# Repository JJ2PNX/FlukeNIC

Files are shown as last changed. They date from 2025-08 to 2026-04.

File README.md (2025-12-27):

# FlukeNIC - Fluke 884x Web Control & Logger Card

## Overview
The Fluke 884x is an outstanding multimeter.  
Even after 40+ years since its production, most units still function properly and maintain excellent accuracy.  
It's likely more reliable than many cheap modern benchtop meters.  
Its value increases when used in ways unique to benchtop instruments, beyond what handheld meters offer.  
GPIB was the traditional method, but a bit far from modern solution.  
I developed built-in web control and logger card that replaces the original GPIB board.  
NIC ... acronym of Network Interface Card.

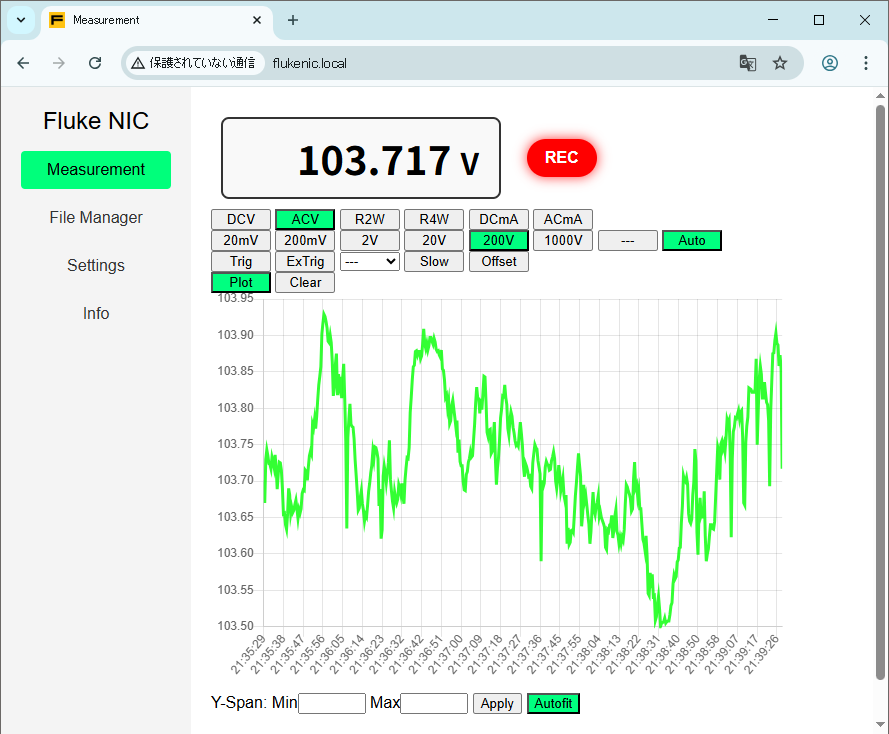
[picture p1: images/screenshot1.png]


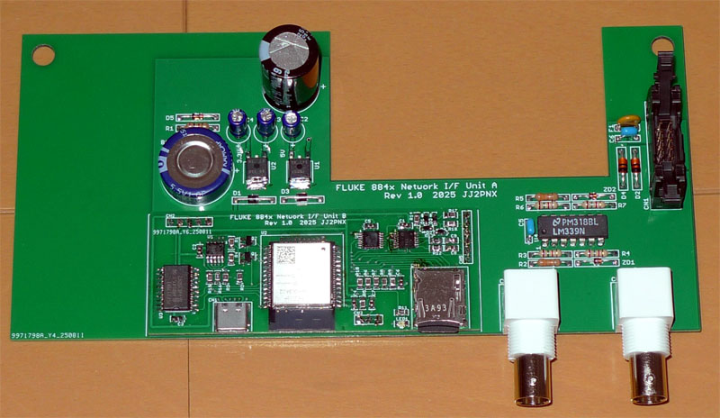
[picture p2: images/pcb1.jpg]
pcb1


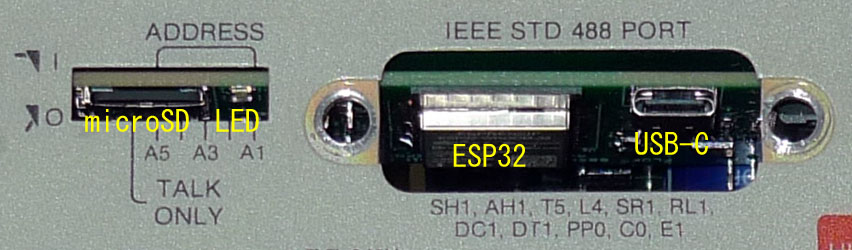
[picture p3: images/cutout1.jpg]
cutout1


---

## Features of This Card
- **WiFi Connectivity**
- **Web-based Control**
- **SD Card Stand-alone Logging**
- **Built-in, No modifications to the main unit required**

---

## How to Get

### 1. Hardware
Currently, no pre-assembled units or kits are available. Please build from the PCB.  
PCB fabrication files (UnitA/B.zip) are for JLCPCB.  
All necessary design materials are in the *hardware* directory.

### 2. Firmware
#### Method 1: Using ESP-IDF

1. Set up the ESP-IDF environment.
2. Clone the repository.
3. Refer to `firmware/README.md` for firmware download instructions.

#### Method 2: Using Flash Download Tool

1. Download **Flash Download Tool** from Espressif.  
   https://docs.espressif.com/projects/esp-test-tools/en/latest/esp32/production_stage/tools/flash_download_tool.html
2. Download `merge.bin` from the `firmware` directory to flash memory at address `0x0`.

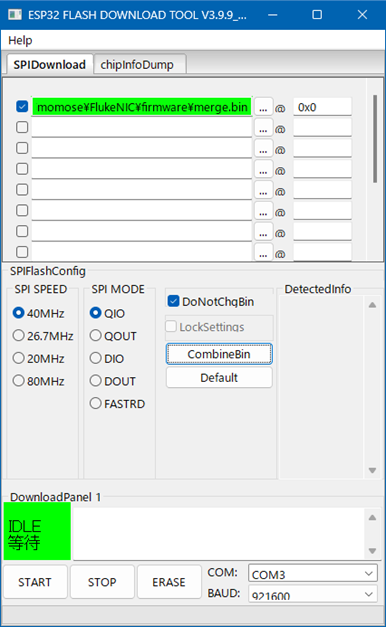
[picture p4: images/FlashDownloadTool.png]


---

## Help / How to Use

### 1. WiFi Connection
By default, FlukeNIC operates as a WiFi access point (AP).
- **SSID:** FlukeNIC  
- **Password:** 88408842  
- **IP Address:** 192.168.4.1  

You can configure WiFi Station settings by connecting to this AP, or by using the WPS push-button method.

#### WPS Push-Button Setup

1. Press the **SRQ** button repeatedly until the **SRQ** indicator lights.
2. When WPS succeeds, the **SRQ** indicator turns off and the **LISTEN** indicator turns on.

Settings are saved to flash memory, so the **LISTEN** indicator should light automatically upon the next power-on.

**Fluke Indicator Summary:**
| Indicator | Meaning |
|---|---|
| SRQ | WiFi WPS Request |
| LISTEN | WiFi Associated |
| TALK | Logging is Active |ESP_ERROR_CHECK

---

### 2. Browser Access
Currently, only DHCP-assigned IPs are supported.  
In most cases, you can access it via:
http://flukenic.local/
If that doesn't work, check the DHCP-assigned IP address on your WiFi router.  
If you got the web interface, you probably won’t need further instructions!

---

### 3. Logging
microSD card is required.  
Start/stop operation can be performed using web-control or front panel **LOCAL** button.  
When logging is active, **TALK** indicator lights up.  
Results can be obtained using File Manager menu, or directly from microSD card, But hot swap is not supported.

---

### 4. Configuration
- Be sure to select the correct model (**8840 / 8842**).
- Other settings are optional.
- All configurations are saved to flash memory.

---

### 5. Troubleshooting
Communication with the Fluke unit is based on reverse-engineering and may malfunction with unexpected inputs.  
In such cases, use the **“Last bytes”** function in the Info menu to inspect the last communication log.  
Feel free to contact me — there may be a fix. Contributions are welcome!

---

### 6. Additional Notes
- SD card hot-swapping is not supported.  
Please insert or remove the card only when the power is off.
- BNC output is not implimented now.

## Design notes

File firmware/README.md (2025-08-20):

## Build and Flash Firmware

```bash
# Move to the firmware directory
$ cd firmware

# Initialize and update submodules
$ git submodule init
$ git submodule update

# Build the firmware (this will take a while)
$ idf.py build

# Flash to device (change the device name to match your PC)
$ idf.py -p /dev/ttyUSB0 flash

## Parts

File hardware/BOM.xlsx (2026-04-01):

UNIT A
 | Parts | Qty | Value | Description
 | BC1 | 1 | 1F | EDLC 1F/5.5V SE-5R5-D105VY (for RTC backup, optional)
 | C1 | 1 | 4700/16V | Electrolytic cap
 | C2, C3, C4 | 3 | 10/16V | Electrolytic cap
 | C5, C6 | 2 | 0.1 | Ceramic cap
 | CN1 | 1 | PS-10PE-D4T2-M1E | Pin header w/Lock
 | CN2, CN3 | 2 | B-057-HP | BNC receptacle
 | D1, D3 | 2 | 1S4 | Low VF generic rect 1A
 | D2, D4 | 2 | 1N4007 | Generic rect 1A
 | D5 | 1 | 1N4148 | Low IR recommended (for RTC backup)
 | F1 | 1 | Not use, use jumper instead
 | R1 | 1 | 1k | Generic resistor
 | R2, R5 | 2 | 33k | Generic resistor
 | R3, R4, R6, R7 | 4 | 1.5k | Generic resistor
 | U1 | 1 | NJM7805SDL1 | Voltage reg 5V, Package TO-252-3
 | U2 | 1 | NJM2845DL1-33 | Voltage reg 3.3V, Low drop, Package TO-252-3
 | U3 | 1 | UNITB
 | U4 | 1 | LM339N
 | ZD1, ZD2 | 2 | RD3.9 | Zener 3.9V
UNIT B
 | Parts | Qty | Value | Description
 | C1, C2, C3, C4, C5, C6, C7 | 7 | 0.1 | Ceramic cap 2012
 | C8, C9 | 2 | 0.01 | Ceramic cap 2012
 | CN1 | 1 | 5077CR-16-SMC2-BK-TR | USB-C jack
 | CN2 | 1 | CON_5P | Pin header single line 100mil
 | CN3 | 1 | CON_3P | Pin header single line 100mil
 | CN4 | 1 | DM3AT-SF-PEJM5 | microSD card socket
 | CN5 | 1 | CON_6P | Pin header single line 100mil
 | D1, D2, D3, D4 | 4 | 1SS355 | Generic SW diode SOD-323
 | LED1 | 1 | PG1112H-TR | Generic LED 2125
 | Q1, Q2 | 2 | 2SC2712 | Generic NPN SC-59
 | R1, R4, R5, R6, R7, R8, R9, R10, R14 | 9 | 10k | Generic resistor 2012
 | R11, R12, R13 | 3 | 470 | Generic resistor 2012
 | R15, R16 | 2 | 3.3k | Generic resistor 2012
 | R17, R18 | 2 | 1k | Generic resistor 2012
 | R2, R3 | 2 | 5.1k | Generic resistor 2012
 | U1 | 1 | CH340K | USB-Serial converter, Backside pad soldering is not required
 | U2 | 1 | ESP-WROOM-32E | Use last letter 'E', Flash >= 4M, Backside pad soldering is not required
 | U3 | 1 | PCF2129 | RTC (optional)
 | U4 | 1 | 74ACT14 | Hex schmitt trigger 5V, TTL input, TSSOP14
 | U5 | 1 | 74LCX14 | Hex schmitt trigger 3.3V, 5V tolerant, TSSOP14

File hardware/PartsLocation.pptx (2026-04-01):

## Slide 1

UNIT A

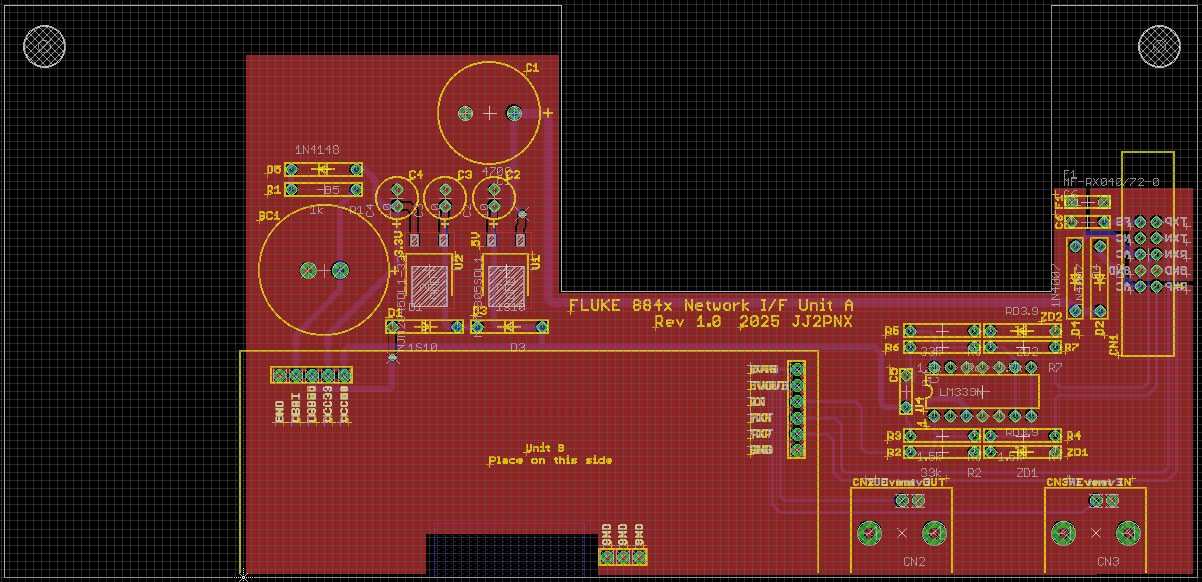
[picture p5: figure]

4700

1N4148

1k

1F

10

10

10

5V

1S4

Jumper

0.1

3V3

1S4

1N4007

1N4007

0.1

33k

1.5k

1.5k

RD3.9

33k

1.5k

1.5k

RD3.9

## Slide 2

UNIT B

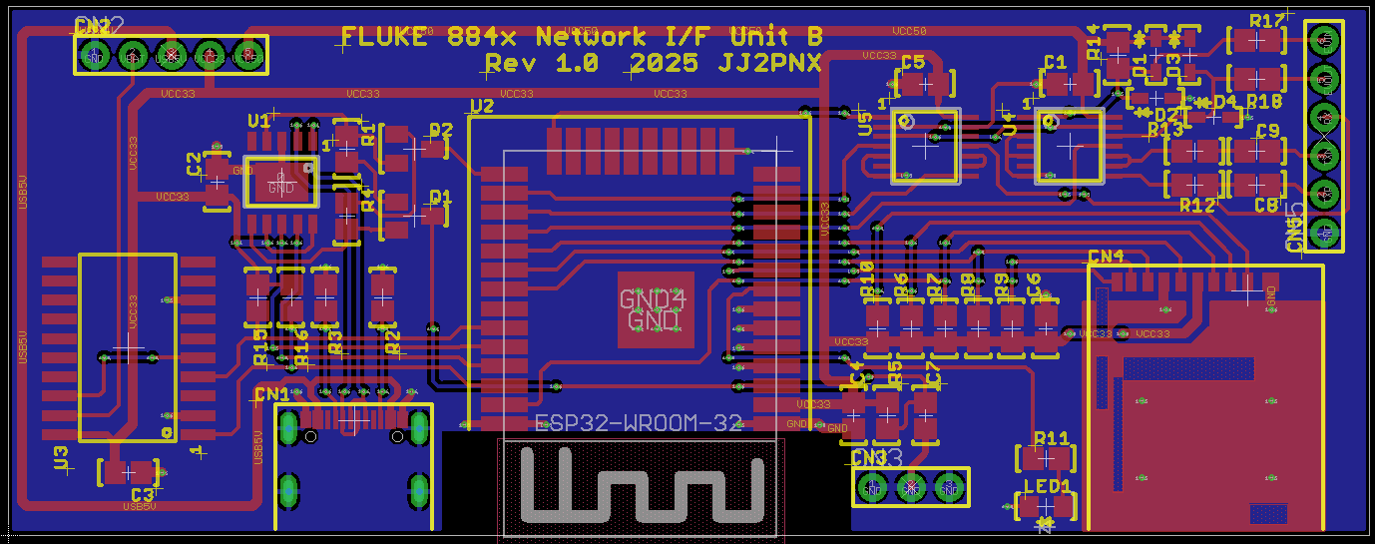
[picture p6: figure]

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
3.3k

10k

470

470

0.01

0.01

3.3k

5.1k

10k

5.1k

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
0.1u x 7
0.01u x 2

Res
470 x3
1k x2
3.3k x2
5.1k x2
10k x9

0.1

0.01

470

1K

3.3k

5.1k

10k

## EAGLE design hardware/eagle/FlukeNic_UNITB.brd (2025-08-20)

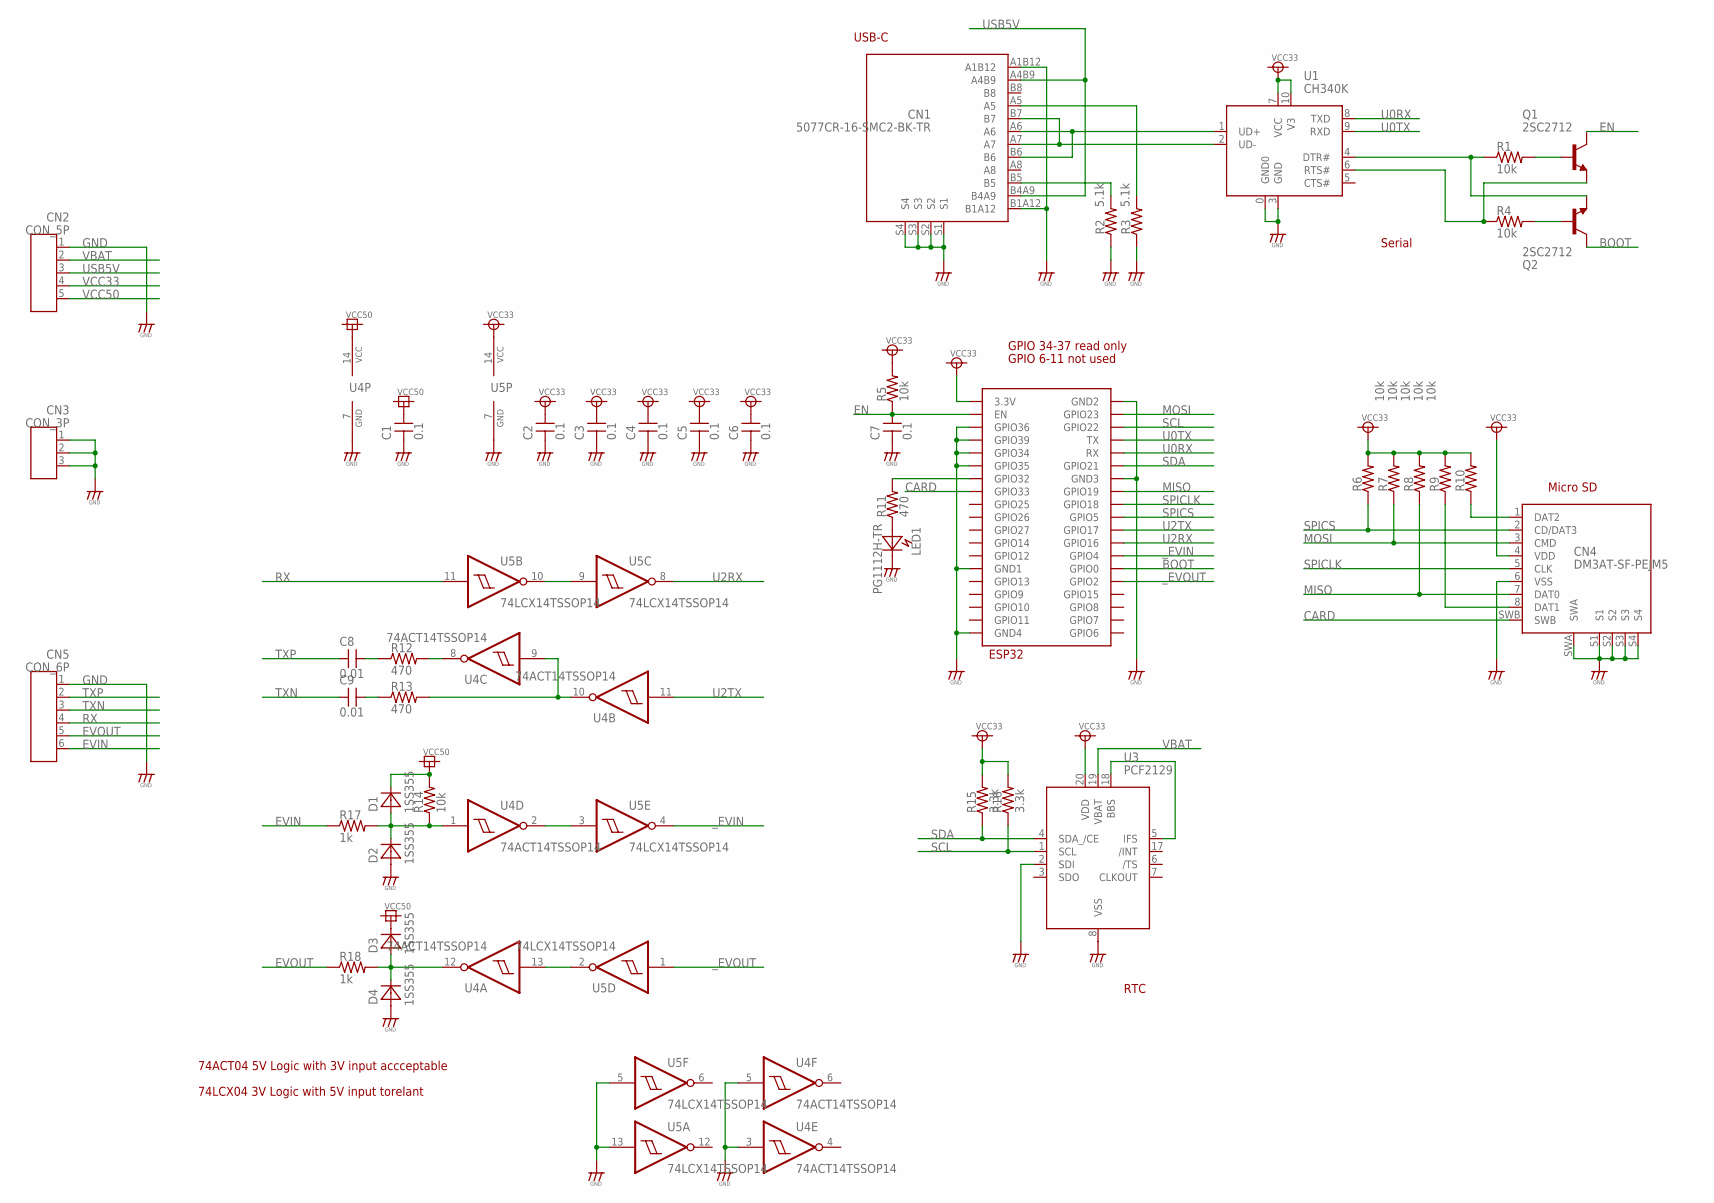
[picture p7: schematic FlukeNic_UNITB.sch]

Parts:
C1, C2, C3, C4, C5, C6, C7: 0.1; C2012
C8, C9: 0.01; C2012
CN1: 5077CR-16-SMC2-BK-TR
CN2: CON_5P; CON_HDR_SIP5
CN3: CON_3P; CON_HDR_SIP3
CN4: DM3AT-SF-PEJM5
CN5: CON_6P; CON_HDR_SIP6
D1, D2, D3, D4: 1SS355; SOD323
LED1: PG1112H-TR; LED2125
Q1, Q2: 2SC2712; SC59
R1, R4, R5, R6, R7, R8, R9, R10, R14: 10k; R2012
R2, R3: 5.1k; R2012
R11, R12, R13: 470; R2012
R15, R16: 3.3k; R2012
R17, R18: 1k; R2012
U1: CH340K; ESSOP10
U2: ESP32-WROOM
U3: PCF2129; SO20
U4: 74ACT14TSSOP14; TSSOP14
U5: 74LCX14TSSOP14; TSSOP14

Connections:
BBS: U3.5 (IFS), U3.18 (BBS)
BOOT: Q2.C, U2.IO0 (GPIO0)
CARD: CN4.SWB, U2.IO33 (GPIO33)
DAT1: CN4.8 (DAT1), R9.1
DAT2: CN4.1 (DAT2), R10.1
EN: C7.2, Q1.C, R5.1, U2.EN
EVIN: CN5.6, R17.1
EVOUT: CN5.5, R18.1
GND: C1.1, C2.1, C3.1, C4.1, C5.1, C6.1, C7.1, CN1.A1B12, CN1.B1A12, CN1.S1, CN1.S2, CN1.S3, CN1.S4, CN2.1, CN3.1, CN3.2, CN3.3, CN4.6 (VSS), CN4.S1, CN4.S2, CN4.S3, CN4.S4, CN4.SWA, CN5.1, D2.1 (A), D4.1 (A), LED1.K, R2.1, R3.1, U1.0 (GND0), U1.3 (GND), U2.GND1, U2.GND2, U2.GND3, U2.GND4, U2.IO34 (GPIO34), U2.IO35 (GPIO35), U2.SENSOR_VN (GPIO39), U2.SENSOR_VP (GPIO36), U3.2 (SDI), U3.8 (VSS), U4.3 (I), U4.5 (I), U4.7 (GND), U5.5 (I), U5.7 (GND), U5.13 (I)
MISO: CN4.7 (DAT0), R8.1, U2.IO19 (GPIO19)
MOSI: CN4.3 (CMD), R7.1, U2.IO23 (GPIO23)
unnamed: U4.13 (I), U5.2 (O)
unnamed: U4.2 (O), U5.3 (I)
unnamed: D1.1 (A), D2.2 (K), R14.1, R17.2, U4.1 (I)
unnamed: D3.1 (A), D4.2 (K), R18.2, U4.12 (O)
unnamed: R13.2, U4.9 (I), U4.10 (O)
unnamed: R12.2, U4.8 (O)
unnamed: U5.9 (I), U5.10 (O)
unnamed: C8.2, R12.1
unnamed: C9.2, R13.1
unnamed: LED1.A, R11.1
unnamed: Q1.B, R1.2
unnamed: Q2.B, R4.2
unnamed: CN1.B5, R2.2
unnamed: CN1.A5, R3.2
unnamed: Q2.E, R1.1, U1.4 (DTR#)
unnamed: Q1.E, R4.1, U1.6 (RTS#)
RX: CN5.4, U5.11 (I)
SCL: R16.1, U2.IO22 (GPIO22), U3.1 (SCL)
SDA: R15.1, U2.IO21 (GPIO21), U3.4 (SDA_/CE)
SPICLK: CN4.5 (CLK), U2.IO18 (GPIO18)
SPICS: CN4.2 (CD/DAT3), R6.1, U2.IO5 (GPIO5)
STATUS: R11.2, U2.IO32 (GPIO32)
TXN: C9.1, CN5.3
TXP: C8.1, CN5.2
U0RX: U1.8 (TXD), U2.RX
U0TX: U1.9 (RXD), U2.TX
U2RX: U2.IO16 (GPIO16), U5.8 (O)
U2TX: U2.IO17 (GPIO17), U4.11 (I)
UD+: CN1.A6, CN1.B6, U1.1 (UD+)
UD-: CN1.A7, CN1.B7, U1.2 (UD-)
USB5V: CN1.A4B9, CN1.B4A9, CN2.3
VBAT: CN2.2, U3.19 (VBAT)
VCC33: C2.2, C3.2, C4.2, C5.2, C6.2, CN2.4, CN4.4 (VDD), R5.2, R6.2, R7.2, R8.2, R9.2, R10.2, R15.2, R16.2, U1.7 (VCC), U1.10 (V3), U2.3V3 (3.3V), U3.20 (VDD), U5.14 (VCC)
VCC50: C1.2, CN2.5, D1.2 (K), D3.2 (K), R14.2, U4.14 (VCC)
_EVIN: U2.IO4 (GPIO4), U5.4 (O)
_EVOUT: U2.IO2 (GPIO2), U5.1 (I)

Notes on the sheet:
GPIO 6-11 not used
GPIO 34-37 read only
USB-C
Micro SD
RTC
Serial
74ACT04 5V Logic with 3V input accceptable
74LCX04 3V Logic with 5V input torelant

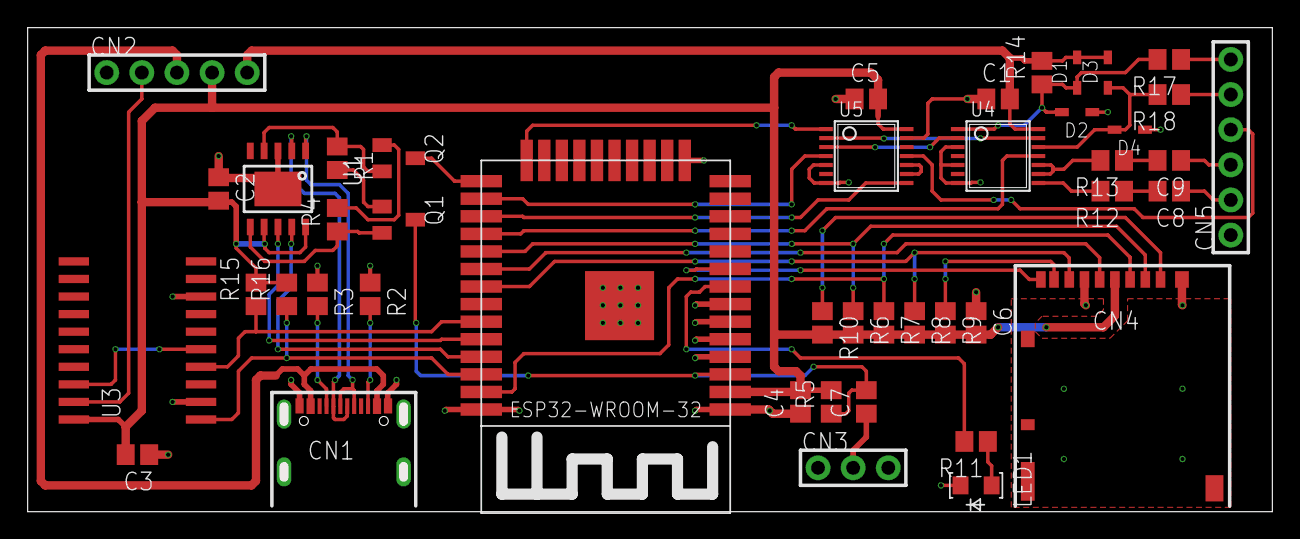
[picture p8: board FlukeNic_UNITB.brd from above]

Board: 2 copper layers, 90.0 x 35.0 mm, 44 parts (0 on the bottom side), 47 nets.

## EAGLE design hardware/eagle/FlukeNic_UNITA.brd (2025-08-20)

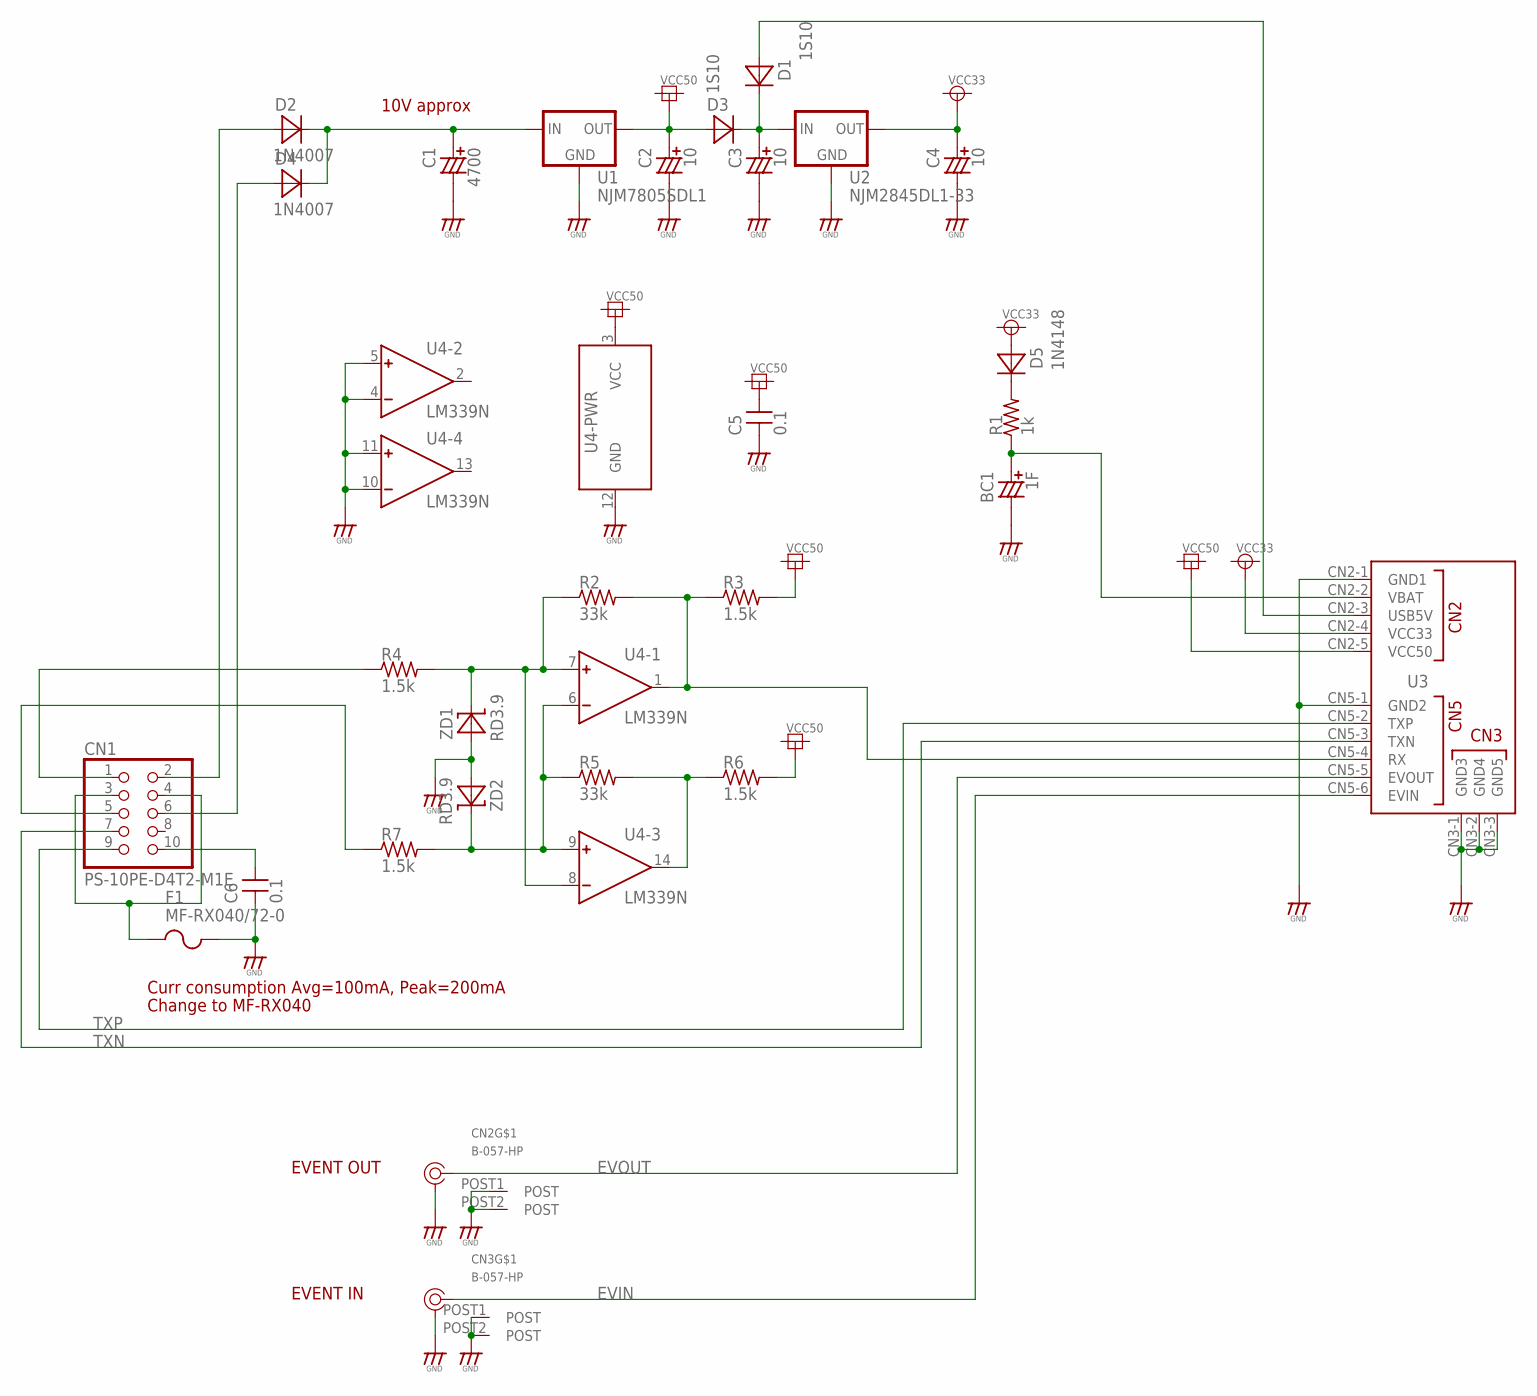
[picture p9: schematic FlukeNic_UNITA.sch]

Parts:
BC1: 1F; SE-5R5-D105VY
C1: 4700; CCAP_16
C2, C3, C4: 10; CCAP_6.5
C5, C6: 0.1; CAP_DIP_2
CN1: PS-10PE-D4T2-M1E
CN2, CN3: B-057-HP
D1, D3: 1S10; DIODE_4_1MM
D2, D4: 1N4007; DIODE_4_1MM
D5: 1N4148; DIODE_4
F1: MF-RX040/72-0; AX_08X02_2P_200
R1: 1k; R_0.25W_4
R2, R5: 33k; R_0.25W_4
R3, R4, R6, R7: 1.5k; R_0.25W_4
U1: NJM7805SDL1; TO252
U2: NJM2845DL1-33; TO252
U3: UNITB
U4: LM339N; DIL14
ZD1, ZD2: RD3.9; DIODE_4

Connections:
EVIN: CN3.HOT, U3.CN5-6 (EVIN)
EVOUT: CN2.HOT, U3.CN5-5 (EVOUT)
GND: BC1.-, C1.-, C2.-, C3.-, C4.-, C5.1, C6.1, CN2.COLD, CN2.POST1 (POST), CN2.POST2 (POST), CN3.COLD, CN3.POST1 (POST), CN3.POST2 (POST), F1.2, U1.2 (GND), U2.2 (GND), U3.CN2-1 (GND1), U3.CN3-1 (GND3), U3.CN3-2 (GND4), U3.CN3-3 (GND5), U3.CN5-1 (GND2), U4.4 (IN-), U4.5 (IN+), U4.10 (IN-), U4.11 (IN+), U4.12 (GND), ZD1.A, ZD2.A
unnamed: R2.1, R4.2, U4.7 (IN+), U4.8 (IN-), ZD1.K
unnamed: R5.1, R7.2, U4.6 (IN-), U4.9 (IN+), ZD2.K
unnamed: R5.2, R6.1, U4.14 (OUT)
unnamed: D5.K, R1.2
unnamed: CN1.3, CN1.4, F1.1
unnamed: C1.+, D2.K, D4.K, U1.1 (IN)
unnamed: CN1.2, D2.A
unnamed: CN1.6, D4.A
unnamed: C3.+, D1.K, D3.K, U2.1 (IN)
unnamed: C6.2, CN1.10
RX: R2.2, R3.1, U3.CN5-4 (RX), U4.1 (OUT)
RXN: CN1.5, R7.1
RXP: CN1.1, R4.1
TXN: CN1.7, U3.CN5-3 (TXN)
TXP: CN1.9, U3.CN5-2 (TXP)
USB5V: D1.A, U3.CN2-3 (USB5V)
VBAT: BC1.+, R1.1, U3.CN2-2 (VBAT)
VCC33: C4.+, D5.A, U2.3 (OUT), U3.CN2-4 (VCC33)
VCC50: C2.+, C5.2, D3.A, R3.2, R6.2, U1.3 (OUT), U3.CN2-5 (VCC50), U4.3 (VCC)

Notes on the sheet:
EVENT OUT
EVENT IN
10V approx
Curr consumption Avg=100mA, Peak=200mA
Change to MF-RX040

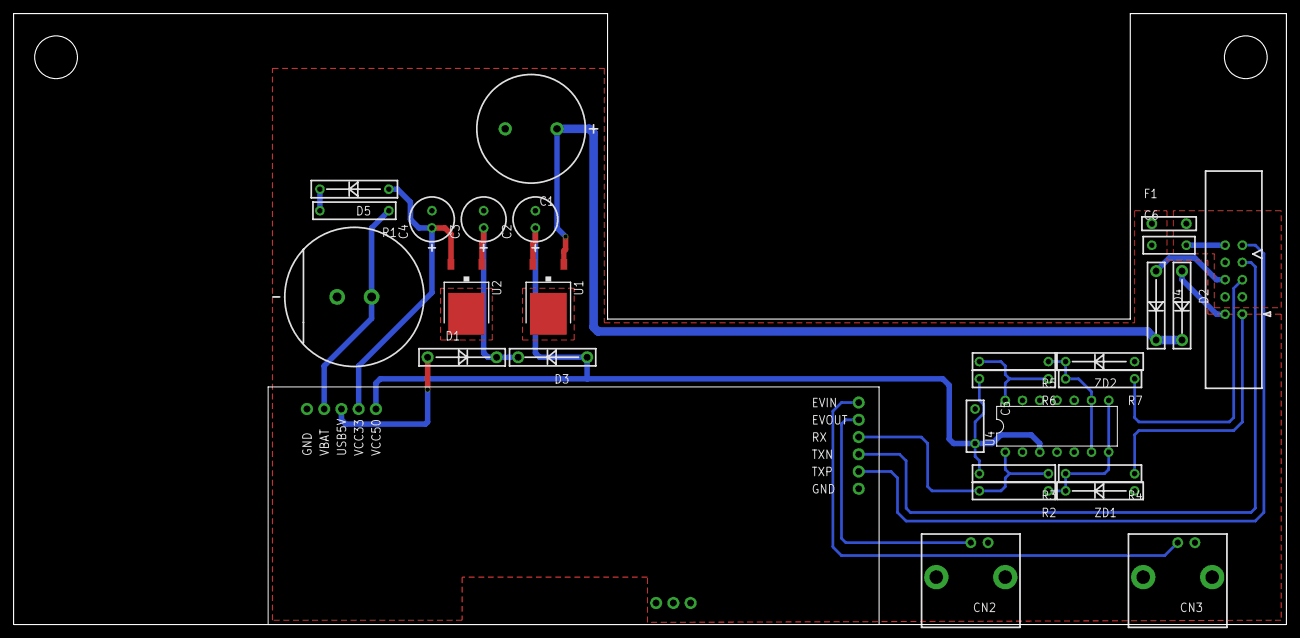
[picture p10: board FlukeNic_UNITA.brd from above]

Board: 2 copper layers, 187.5 x 90.0 mm, 29 parts (0 on the bottom side), 22 nets.

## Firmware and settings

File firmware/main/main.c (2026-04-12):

//   Copyright 2025 H.Momose / JJ2PNX
//
//   Licensed under the Apache License, Version 2.0 (the "License");
//   you may not use this file except in compliance with the License.
//   You may obtain a copy of the License at
//
//       http://www.apache.org/licenses/LICENSE-2.0
//
//   Unless required by applicable law or agreed to in writing, software
//   distributed under the License is distributed on an "AS IS" BASIS,
//   WITHOUT WARRANTIES OR CONDITIONS OF ANY KIND, either express or implied.
//   See the License for the specific language governing permissions and
//   limitations under the License.

#include <string.h>
#include <stdio.h>
#include <stdlib.h>
#include <unistd.h>
#include <sys/stat.h>
#include <esp_log.h>
#include <nvs_flash.h>
#include "freertos/FreeRTOS.h"
#include "freertos/task.h"
#include "freertos/queue.h"
#include "esp_event.h"
#include "esp_check.h"
#include <esp_wifi.h>
#include "nvs_flash.h"
#include "driver/gpio.h"
#include "mdns.h"
#include "fluke.h"
#include "webserver.h"
#include "mount.h"
#include "rtc_pcf2129.h"
#include "wifi.h"
#include "nettime.h"
#include "settings.h"
#include "logger.h"
#include "dataout.h"

#define GPIO_LED    32
#define GPIO_EVIN   04
#define GPIO_EVOUT  02

static const char *TAG = "Main";

// Save console log to sdcard(for debug)
// Record drop may occur when used with FAST sampling
#ifdef CONFIG_FLUKENIC_LOG_SDCARD
static FILE* log_file = NULL;

static int my_log_vprintf(const char *fmt, va_list args) {
    if (log_file) {
        vfprintf(log_file, fmt, args);
        fflush(log_file);
        fsync(fileno(log_file));
    }
    return vprintf(fmt, args);
}

static void init_logging_to_file(void) {
    struct stat st;
    if(stat("/sdcard/log", &st) == -1){
        mkdir("/sdcard/log", 0755);
    }
    time_t tt;
    time(&tt);
    struct tm stm;
    localtime_r(&tt, &stm);
    char filename[128];
    sprintf(filename, "/sdcard/log/log%02d%02d%02d-%02d%02d%02d.txt",
        stm.tm_year %100, stm.tm_mon +1, stm.tm_mday, stm.tm_hour, stm.tm_min, stm.tm_sec);
    log_file = fopen(filename, "w");
    if (log_file) {
        esp_log_set_vprintf(my_log_vprintf);
    } else {
        ESP_LOGE("LOG", "Failed to open log file");
    }
}
#endif

static void connect_handler(void* arg, esp_event_base_t event_base, int32_t event_id, void* event_data)
{
    ESP_LOGI(TAG, "connect_handler");
    fluke_annun(ANNUN_LISTEN, true);
    if(settings.flags & FL_NTPUSE){
        nettime_set(settings.ntp_server);
    }
}

static void disconnect_handler(void* arg, esp_event_base_t event_base, int32_t event_id, void* event_data)
{
    ESP_LOGI(TAG, "disconnect_handler");
    fluke_annun(ANNUN_LISTEN, false);
}

static void srq_repeative_hits(void)
{
    TickType_t tick = pdTICKS_TO_MS(xTaskGetTickCount());
    static TickType_t prevtick = 0;
    static int nhits = 0;
    if(tick - prevtick < 500){
        nhits ++;
    } else {
        nhits = 0;
    }
    prevtick = tick;
    if(nhits > 5){
        nhits = 0;
        wifi_start_wps();
    }
}

static QueueHandle_t interruptQueue;
static void IRAM_ATTR gpio_interrupt_handler(void *args)
{
    int pinNumber = (int)args;
    xQueueSendFromISR(interruptQueue, &pinNumber, NULL);
}

static fluke_config_t config_last;

static void extrig_task(void *params)
{
    int pinNumber;
    while(true){
        if(xQueueReceive(interruptQueue, &pinNumber, pdMS_TO_TICKS(100))){
            if(config_last.flags & FL_EXTRIG && extsrc < 0){
                int level = gpio_get_level(pinNumber);
                if( (extsrc == EXTSRC_BNC_POS && level == 1) || (extsrc == EXTSRC_BNC_NEG && level == 0)){
                    // BNC Trig
                    fluke_trig();
                }
            }
        } else {
            if(config_last.flags & FL_EXTRIG && extsrc > 0){
                time_t tt;
                static time_t ttprev;
                time(&tt);
                if((tt != ttprev) && (tt % extsrc == 0)){
                    // Timer Trig
                    fluke_trig();
                    ttprev = tt;
                }
            }
        }
    }
}

QueueHandle_t fluke_event_queue;

void app_main(void)
{
    // fluke_init must run at first stage of startup, otherwise fluke does not recognize card.
    // see esp-idf document to improve startup time.
    // https://docs.espressif.com/projects/esp-techpedia/en/latest/esp-friends/advanced-development/performance/reduce-boot-time.html
    ESP_ERROR_CHECK(fluke_init(100, &fluke_event_queue));
    
    gpio_reset_pin(GPIO_LED);
    gpio_reset_pin(GPIO_EVIN);
    gpio_reset_pin(GPIO_EVOUT);
    gpio_set_direction(GPIO_LED, GPIO_MODE_OUTPUT);
    gpio_set_direction(GPIO_EVIN, GPIO_MODE_INPUT);
    gpio_set_direction(GPIO_EVOUT, GPIO_MODE_OUTPUT);

    gpio_set_level(GPIO_LED, 1);

    // External trigger
    gpio_set_intr_type(GPIO_EVIN, GPIO_INTR_ANYEDGE);
    gpio_install_isr_service(0);
    gpio_isr_handler_add(GPIO_EVIN, gpio_interrupt_handler, (void *)GPIO_EVIN);
    interruptQueue = xQueueCreate(10, sizeof(int));
    assert(interruptQueue);
    assert(xTaskCreate(extrig_task, "extrig_task", 3072, NULL, 1, NULL) == pdPASS);

    // Load settings
    esp_err_t ret = nvs_flash_init();
    if (ret == ESP_ERR_NVS_NO_FREE_PAGES || ret == ESP_ERR_NVS_NEW_VERSION_FOUND) {
        ESP_LOGI(TAG, "nvs_flash_erase");
        ESP_ERROR_CHECK(nvs_flash_erase());
        ret = nvs_flash_init();
    }
    ESP_ERROR_CHECK(ret);
    settings_load();
    fluke_setmodel(settings.flags & FL_8840A ? true : false);

    // Set Date/Time from RTC
    setenv("TZ", settings.timezone, 1);
    tzset();
    rtc_pcf2129_init();
    rtc_pcf2129_hctosys();

    // Network
    ESP_ERROR_CHECK(esp_netif_init());
    ESP_ERROR_CHECK(esp_event_loop_create_default());
    ESP_ERROR_CHECK(esp_event_handler_register(IP_EVENT, IP_EVENT_STA_GOT_IP, &connect_handler, NULL));
    ESP_ERROR_CHECK(esp_event_handler_register(WIFI_EVENT, WIFI_EVENT_STA_DISCONNECTED, &disconnect_handler, NULL));
    wifi_start();

    // mDNS
    ESP_ERROR_CHECK(mdns_init());
    mdns_hostname_set(settings.hostname);

    // Mount storage
    if(mount_spiffs("/spiffs") != ESP_OK){
        ESP_LOGE(TAG, "SPIFFS mount failed, please update spiffs");
    }
    if(mount_sdcard("/sdcard") != ESP_OK){
        ESP_LOGW(TAG, "SD mount failed");
    }

    // Save console log to sdcard
#ifdef CONFIG_FLUKENIC_LOG_SDCARD
    init_logging_to_file();
#endif

    httpd_handle_t server = start_webserver();
    assert(server);
    
    fluke_event_t event;
    // Clear fluke event queue
    while(xQueueReceive(fluke_event_queue, (void *)&event, 0) == pdPASS) continue;
    // Get fluke event and process it
    while(true){
        if(xQueueReceive(fluke_event_queue, (void *)&event, pdMS_TO_TICKS(100))==pdPASS){
            switch(event.type){
            case EVENT_MEAS:
                //ESP_LOGI(TAG, "EVENT_MEAS count=%d, range=%d", event.meas.count, event.meas.range);
                ws_send_fluke_event(server, event);
                logger_record(&event, &config_last);
                dataout_send(&event, &config_last);
                break;
            case EVENT_CONFIG:
                ESP_LOGI(TAG, "EVENT_CONFIG func=%d, range=%d, speed=%d, flags=%d", 
                    event.config.func, event.config.range, event.config.speed, event.config.flags);
                config_last = event.config;
                ws_send_fluke_event(server, event);
                break;
            case EVENT_ERROR:
                ESP_LOGI(TAG, "EVENT_ERROR error=%d", event.errnum);
                ws_send_fluke_event(server, event);
                break;
            case EVENT_SRQ:
                ESP_LOGI(TAG, "EVENT_SRQ SRQ Pressed");
                srq_repeative_hits();
                break;
            case EVENT_LOCAL:
                ESP_LOGI(TAG, "EVENT_LOCAL LOCAL Pressed");
                if(~settings.flags & FL_LOGLOCAL) break;
                // fall through
            case EVENT_AUX: // Web rec button
                event.type = EVENT_LOCAL;
                //fluke_gotolocal();
                logger_startstop();
                ws_send_fluke_event(server, event);
                break;
            default:
                ESP_LOGW(TAG, "UNKNOWN EVENT");
                break;
            }
        }
 
        // LED blinker
        if(pdTICKS_TO_MS(xTaskGetTickCount()) % 1000 > 500){
            gpio_set_level(GPIO_LED, 1);
        } else {
            gpio_set_level(GPIO_LED, 0);
        }
    }
}

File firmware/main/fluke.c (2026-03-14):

//   Copyright 2025 H.Momose / JJ2PNX
//
//   Licensed under the Apache License, Version 2.0 (the "License");
//   you may not use this file except in compliance with the License.
//   You may obtain a copy of the License at
//
//       http://www.apache.org/licenses/LICENSE-2.0
//
//   Unless required by applicable law or agreed to in writing, software
//   distributed under the License is distributed on an "AS IS" BASIS,
//   WITHOUT WARRANTIES OR CONDITIONS OF ANY KIND, either express or implied.
//   See the License for the specific language governing permissions and
//   limitations under the License.

#include "freertos/FreeRTOS.h"
#include "freertos/task.h"
#include "driver/uart.h"
#include "sdkconfig.h"
#include "esp_log.h"
#include "semaphore.h"
#include "esp_system.h"
#include "esp_event.h"
#include "lwip/err.h"
#include "lwip/sys.h"
#include "fluke.h"
// Required to acheve 100sp/s rate
#ifndef CONFIG_UART_ISR_IN_IRAM
#error "Set CONFIG_UART_ISR_IN_IRAM"
#endif

#ifndef ARRAY_LENGTH
#define ARRAY_LENGTH(X)     (sizeof(X)/sizeof(X[0]))
#endif

//#define DUMP
#define UART_TXD 17
#define UART_RXD 16
#define UART_RTS UART_PIN_NO_CHANGE
#define UART_CTS UART_PIN_NO_CHANGE
#define UART_BAUD_RATE 62500  
#define UART_PORT_NUM 2
#define TASK_STACK_SIZE 3072    // Bytes (esp-idf uses bytes, not words)
#define TASK_PRIO   10

#define HOSTVALUE(X)  ((X) & 0x0F)      // Ignore upper 4 bits to get value from host (decode)
#define CARDVALUE(X)  (X)

static const char *TAG = "Fluke";

static int nbreak = 0;
static int nparity = 0;
static int nframe = 0;
// Card transmit data
static char txdata[32];
static int txlen = 0;
static int txindex = 0;
static bool txslot = false;
static SemaphoreHandle_t txmutex;
static char txlast[16] = {0};
static int txcount  = 0;
// Host receive data
static char rxdata[32];
static int rxindex = 0;
static bool rxslot = false;
static QueueHandle_t rxqueue;
static char rxlast[16] = {0};
static int rxcount = 0;

static fluke_annun_t annunciator = ANNUN_NONE;
static bool registered = false;
static bool is8840a = false;
static unsigned int msgq_full_count = 0;

////////////////////////////////////////////////
// Internal prototypes (only required)
static void fluke_invoketx();
static void cardmsg_45(int datum);

////////////////////////////////////////////////
// Internal functions

// Send 1 byte to main
static void fluke_putc(char c)
{
    uart_write_bytes(UART_PORT_NUM, &c, 1);
#ifdef DUMP
    ESP_LOGI(TAG, "Write: %02x", c);
#endif
    txlast[txcount%sizeof(txlast)] = c;
    txcount ++;
}

// Bootup emulation of GPIB card
static void register_card()
{
    ESP_LOGI(TAG, "register_card");
    fluke_putc(0x48);
    vTaskDelay(1000 / portTICK_PERIOD_MS);
    txlen = 0;
    txindex = 0;
    txslot = false;
    //cardmsg_45(0);  // NotTalk(0), Talk(2)
    cardmsg_45(annunciator);
    fluke_invoketx();
    registered = true;
}

////////////////////////////////////////////////
// Card message maker

// Card msg 0x41 Trigger
static void cardmsg_41(void)
{
    txdata[txlen++] = 0x41; // Header (Msg id)
    txdata[txlen++] = 0x40; // Footer
}

// Card msg 0x43 Disp GPIB addr etc.
// (P, Q, x, x) ... Disp GPIB addr(PQ) (P < 4)
// (8, R, x, x) ... Disp off(R=1) / on(R=0)
// (C, 1, x, x) ... Selftest(C is 0xC)
static void cardmsg_43(int a1, int a2, int b1, int b2)
{
    txdata[txlen++] = 0x43; // Header (Msg id)
    txdata[txlen++] = CARDVALUE(a1); // GPIB addr 10's etc
    txdata[txlen++] = CARDVALUE(a2); // GPIB addr 1's etc
    txdata[txlen++] = CARDVALUE(b1); // Unknown
    txdata[txlen++] = CARDVALUE(b2); // Unknown
    txdata[txlen++] = 0x40; // Footer
}

// Card msg 0x44 Offset on/off
static void cardmsg_44(bool offset)
{
    txdata[txlen++] = 0x44; // Header (Msg id)
    txdata[txlen++] = offset ? CARDVALUE(1) : CARDVALUE(0);
    txdata[txlen++] = 0x40; // Footer
}

// Card msg 0x45 Annunciator
// 0x01 ... REMOTE, Lock local control
// 0x02 ... TALK
// 0x04 ... LISTEN
// 0x08 ... SRQ     Latter 3 are probably indicator only 
static void cardmsg_45(int datum)
{
    txdata[txlen++] = 0x45; // Header (Msg id)
    txdata[txlen++] = CARDVALUE(datum);
    txdata[txlen++] = 0x40; // Footer
}

#if 0
// Card msg 0x46 Get user-defined message
static void cardmsg_46(void)
{
    txdata[txlen++] = 0x46; // Header (Msg id)
    txdata[txlen++] = 0x40; // Footer
}

// Card msg 0x47 Get CAL rom data
static void cardmsg_47(void)
{
    txdata[txlen++] = 0x47; // Header (Msg id)
    txdata[txlen++] = 0x40; // Footer
}
#endif

// Card msg 0x49 Make host tell config, host will respond 0x65 config
static void cardmsg_49(void)
{
    txdata[txlen++] = 0x49; // Header (Msg id)
    txdata[txlen++] = 0x40; // Footer
}

// Card msg 0x4B Set Func/Range/Speed/Trig
static void cardmsg_4b(int func, int range, int speed, int trig)
{
    if(is8840a && range > 2) range --;  // 8840a/8842a range is differ by one
    txdata[txlen++] = 0x4b; // Header (Msg id)
    txdata[txlen++] = CARDVALUE(func);
    txdata[txlen++] = CARDVALUE(range);
    txdata[txlen++] = CARDVALUE(speed);
    txdata[txlen++] = CARDVALUE(trig);
    txdata[txlen++] = 0x40; // Footer
}

////////////////////////////////////////////////
// Host message handlers

static void set_timestamp(fluke_event_t *event)
{
    static time_t lastsec = 0;
    static struct tm lasttm;
    gettimeofday(&event->timestamp.tv, NULL);
    if(event->timestamp.tv.tv_sec != lastsec){
        lastsec = event->timestamp.tv.tv_sec;
        localtime_r(&lastsec, &lasttm);
    }
    event->timestamp.tm_local = lasttm;
}

// Host msg 0x61 Sample complete
static void hostmsg_61(void)
{
}

// Host msg 0x63 SRQ key pressed
static void hostmsg_63(void)
{
    fluke_event_t event;
    event.type = EVENT_SRQ;
    set_timestamp(&event);
    if(xQueueSendToBack(rxqueue, &event, 0) == errQUEUE_FULL){
        // Discard old event if append failed
        // This mostly occurs when SD card writing falls behind during FAST rate
        fluke_event_t dummy;
        xQueueReceive(rxqueue, &dummy, 0);
        xQueueSendToBack(rxqueue, &event, 0);
        ESP_LOGW(TAG, "Event queue full");
        msgq_full_count++;
    }
}

// Host msg 0x64 LOCAL key pressed
// Genuine behavior
// In REMOTE mode, card sends 45-80-40 msg to bring host LOCAL mode
// In LOCAL mode, card sends 43 msg to display gpib addr
static void hostmsg_64(void)
{
    // cardmsg_43(0, 1, 0, 0);  // Display GPIB addr 01
    fluke_event_t event;
    event.type = EVENT_LOCAL;
    set_timestamp(&event);
    if(xQueueSendToBack(rxqueue, &event, 0) == errQUEUE_FULL){
        // Discard old event if append failed
        // This mostly occurs when SD card writing falls behind during FAST rate
        fluke_event_t dummy;
        xQueueReceive(rxqueue, &dummy, 0);
        xQueueSendToBack(rxqueue, &event, 0);
        ESP_LOGW(TAG, "Event queue full");
        msgq_full_count++;
    }
}
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

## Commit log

2025-08-14 software 1st import
    [partitions.csv]
2025-08-18 fix not boot with brand-new pcf2129, change dir from software to firmware, append readme
    [partitions.csv]
2025-08-20 Add hardware
    [BOM.xlsx, FlukeNic_UNITA.brd, FlukeNic_UNITA.sch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]
2025-08-31 Add UDP data out, esp-idf esp32 chip info
2026-02-08 Change Fluke host I/O from 8-bit no parity to 7-bit odd parity, and improve stability. Add Wi-Fi TX power setting, Wi-Fi AP information, and IP address to the info page.
    [fluke.c]
2026-04-01 Fuse F1 not used, use jumper instead.
    [FlukeNic_UNITA.sch]
2026-04-01 Update BOM.xlsx, PartsLocation.pptx indicates F1 as jumper.
    [BOM.xlsx]
